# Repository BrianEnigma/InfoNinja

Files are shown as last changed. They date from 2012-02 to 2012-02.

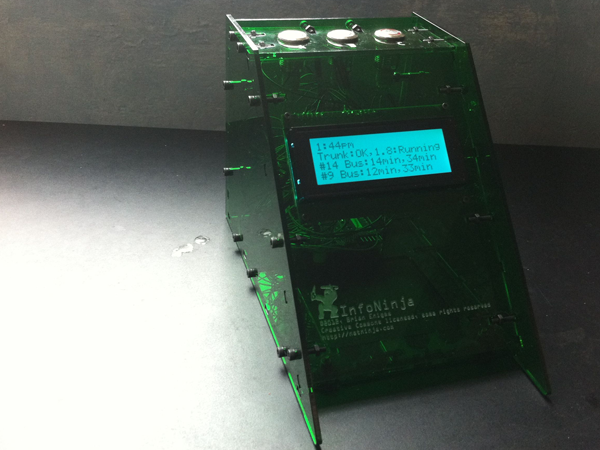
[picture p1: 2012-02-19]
design_documents/front_view.png

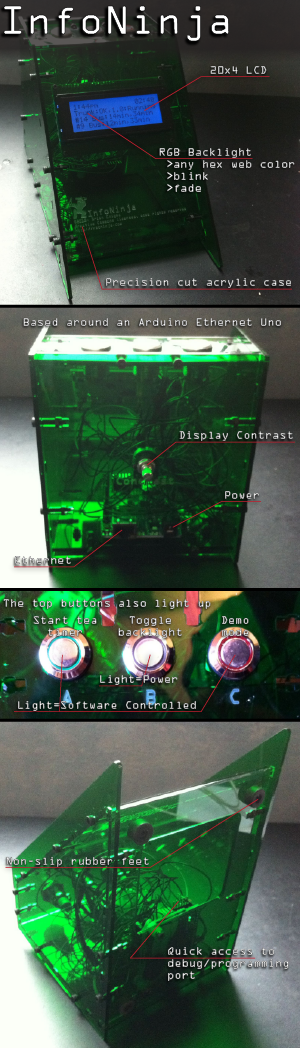
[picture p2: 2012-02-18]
design_documents/hardware_overview.png

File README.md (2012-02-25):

#InfoNinja

InfoNinja is an Open Source Ethernet-connected desktop heads-up display. It works in tandem with a desktop computer to give you an at-a-glance secondary display of both text and ambient (color/blink/fade) information.

It is also a tea timer.

More detailed information and instructions about InfoNinja can be found at <http://netninja.com/projects/infoninja/>.

#Overview

There are two pieces to InfoNinja, each split into its own section:

 - [Hardware/Firmware](http://netninja.com/projects/infoninja/hardware/)
 - [Software](http://netninja.com/projects/infoninja/software/)

The hardware is the InfoNinja box itself.  The firmware runs within InfoNinja and provides a lightweight REST-enabled web server.  It receives commands over the network and updates the text and lights.

The software runs on a desktop computer.  It can query various environmental conditions — things like weather, bus times, the stock market, recent Tweets, email counts, automated software builds — and then tell InfoNinja to do things like flash red or print status.

The two work in unison to give you any information you need.

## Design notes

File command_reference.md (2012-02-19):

#InfoNinja Command Reference

for firmware version 1.0

##Display Text

###URL

    http://x.x.x.x/print?n:my_text

###Parameters

- n : the 0-based line number to replace
- my_text : the URL-encoded text to write

###Description

This command displays text on the given line (from 0 to 3).  The entire line will be replaced with the text you give it, so any previously-displayed text will get overwritten, even if you're writing a shorter line.

The text is URL-encoded, so you will have to escape non-alphanumerics with percent-hex equivalents.  For example, "hello world" would be escaped to "hello%20world".  

You have up to 20 characters (after un-escaping) on each line, but remember that the last 5 characters of the first line (line 0) might be obscured by the tea timer countdown.

##Set BacklightColor

###URL

    http://x.x.x.x/lcdcolor?rrrgggbbb

###Parameters

- rrr : The 3-digit red value, from 000 to 255
- ggg : The 3-digit green value, from 000 to 255
- bbb : The 3-digit blue value, from 000 to 255

###Description

This command sets the LCD backlight color to any arbitrary value.  You should keep a few things in mind:

- The user can disable the solid-color backlight with the backlight toggle button.
- If you specify a backlight blink mode, that takes precedence over the solid color you define here.
- If you want to do more complex animations (such as blinking or fading), this is probably not the command to use.  The variable network delay can be unpredictable.  You likely want to use "Set Blink/Fade Mode" command, possibly extending that command to do a custom color pattern, if that is your desire.

##Set Button Lights

###URL

    http://x.x.x.x/buttonled?n

###Parameters

- n : light mode

####Description

This command enables, disables, or blinks the button LEDs.  The possible values for light mode are:

- 0 : disable button lights
- 1 : enable button lights
- 2 : blink button lights (the light toggles every second)

##Set Blink/Fade Mode

###URL

    http://x.x.x.x/blinkmode?n

###Parameters

- n : light mode

###Description

This command enables or disables the LCD backlight blink/fade mode.  The possible values for light mode are:

- 0 : Disable blinking/fading
- 1 : flash between bright yellow and dim yellow once a second
- 2 : flash between bright red and dim red once a second
- 3 : flash between bright blue and dim blue once a second
- 4 : fade between bright yellow and dim yellow
- 5 : fade between bright red and dim red
- 6 : fade between bright blue and dim blue

Note that this setting overrides any background color you may have set via the background-color command.

Also note that manually enabling the blue fade mode through software may be misleading.  This mode is automatically enabled if InfoNinja has not been communicated to in the last few minutes.  It is used to indicate that the displayed data may be stale.

##Button State

Retrieving the button state from the desktop software is specifically *not* supported.  Because the web server is single-threaded, it does not allow for cool Ajax-like blocking web requests (where the incoming web request is accepted, but holds off writing to it until the button state changes, simulating a synchronous action from an asynchronous query).  The desktop software would have to continually poll InfoNinja for the button state, then send updates to respond accordingly.  This introduces enough latency as to provide a rather poor user experience.  For this reason, the ability to query buttons has been intentionally omitted.

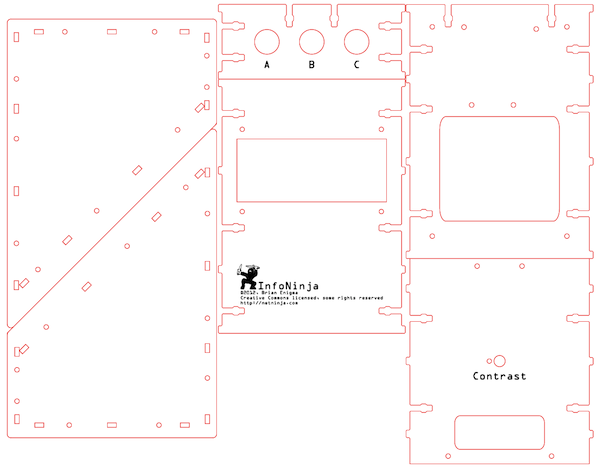
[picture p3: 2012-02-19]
design_documents/lasercut_preview.png

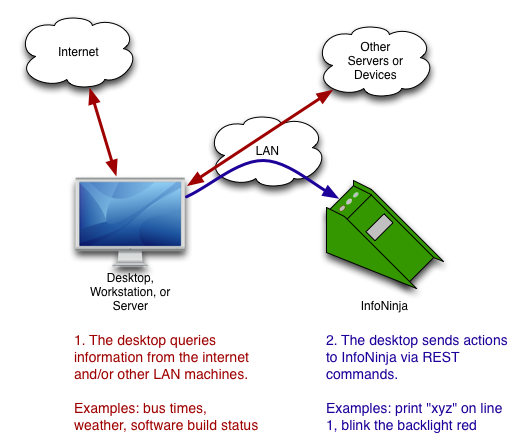
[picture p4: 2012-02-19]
design_documents/network_block_diagram.png

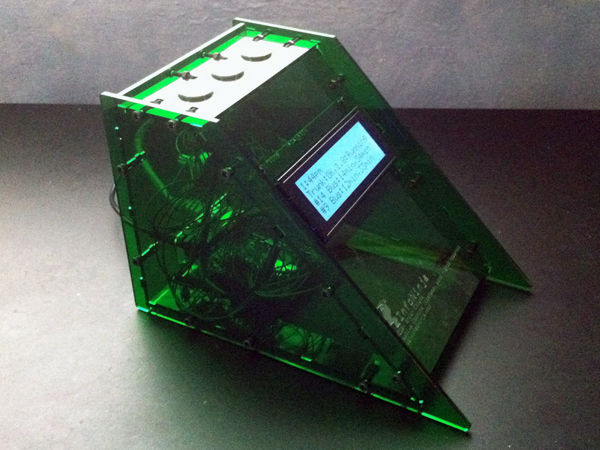
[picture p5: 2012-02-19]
design_documents/side_view.png

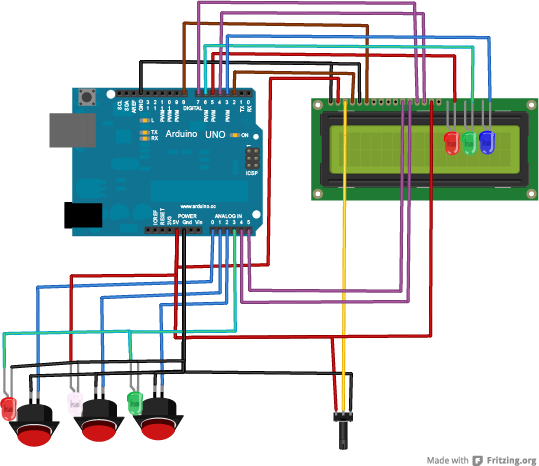
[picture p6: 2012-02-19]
schematics/InfoNinjaSchematic.png

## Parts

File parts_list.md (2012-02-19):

#InfoNinja Parts List

1. Obtain the tools you might need
    - Wire
    - Solder
	- [Headers](http://www.adafruit.com/products/400) to connect to the Arduino (or a breakout board such as the [Proto-Shield](http://www.adafruit.com/products/51) or [Wingshield](http://www.adafruit.com/products/196), if that’s your style)
    - etc.
2. Obtain electronics parts
    - [Arduino Ethernet](http://www.adafruit.com/products/418)
	- [AC Adapter](http://www.adafruit.com/products/63)
    - [20x4 RGB LCD](http://www.adafruit.com/products/499)
    - [Contrast knob](http://www.adafruit.com/products/562) (10K panel-mount potentiometer)
    - [Red LED pushbutton](http://www.adafruit.com/products/559)
    - [Green LED pushbutton](http://www.adafruit.com/products/560)
    - [White LED pushbutton](http://www.adafruit.com/products/558)
    - Ethernet cable
    - [FTDI Friend](https://www.adafruit.com/products/284) (for programming)
    - Mini-USB cable (for programming)
3. Obtain hardware
    - [16M3 screws](http://www.mcmaster.com/#91290A120), #91290A120
    - [M3 nuts](http://www.mcmaster.com/#98676A100), #98676A100
    - [10M2 screws](http://www.mcmaster.com/#91290A017), #91290A017
    - [M2 nuts](http://www.mcmaster.com/#90591A111), #90591A111
    - [8M3 Spacers](http://www.mcmaster.com/#93657A143), #93657A143
	- [M3 Nylon Washers](http://www.mcmaster.com/#95610A130), #95610A130
    - [Rubber feet](http://www.mcmaster.com/#9540K51), #9540K51
4. Obtain laser-cut parts
    - Laser-cut the case

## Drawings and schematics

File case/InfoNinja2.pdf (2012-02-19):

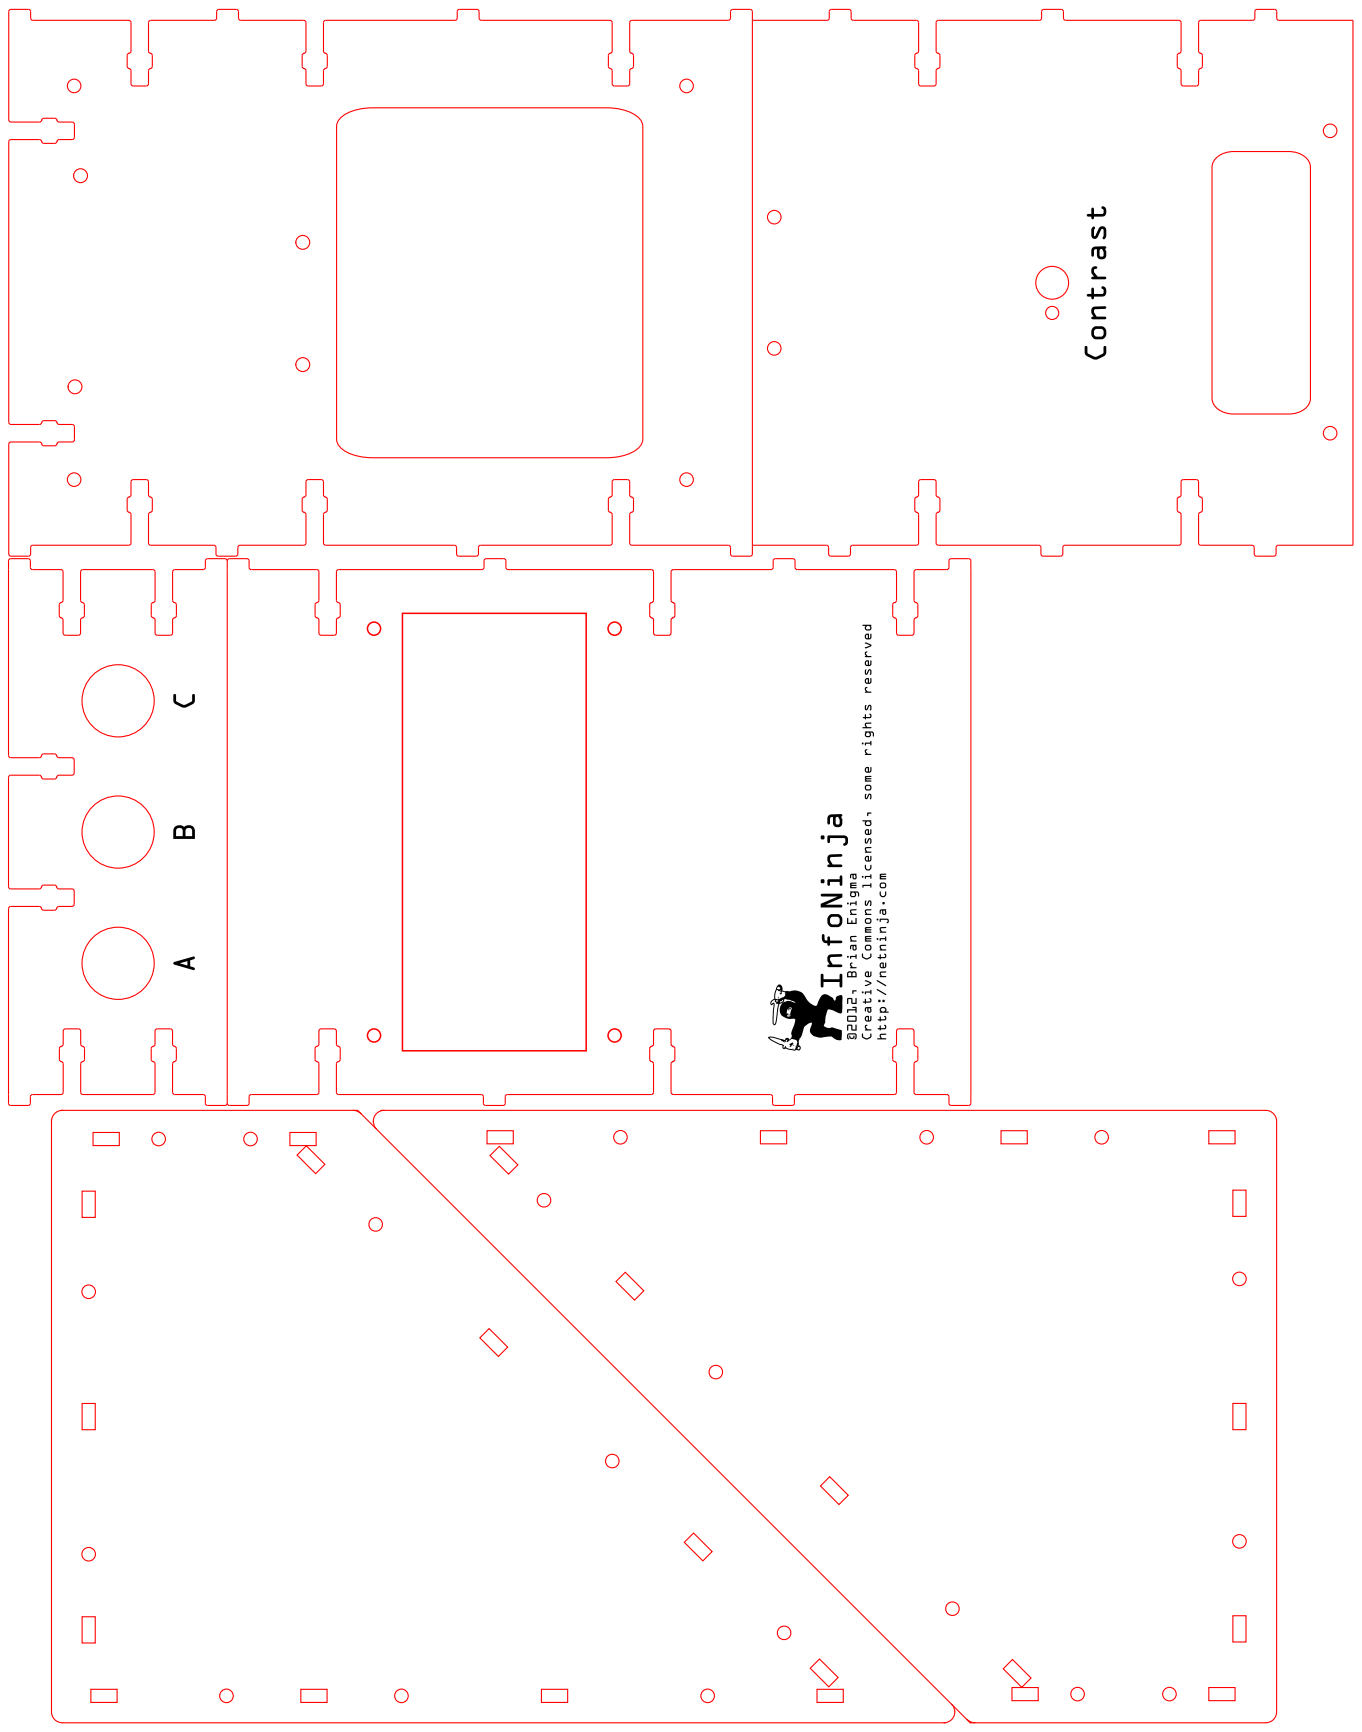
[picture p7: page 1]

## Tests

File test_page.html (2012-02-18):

InfoNinja's IP Address:

- LCD Text
  - Print Hello (http://10.0.1.15/print?0:HELLO)
  - Print Ninja (http://10.0.1.15/print?0:Ninja)
- Button LEDs
  - Button Lights On (http://10.0.1.15/buttonled?1)
  - Button Lights Off (http://10.0.1.15/buttonled?0)
  - Button Lights Blink (http://10.0.1.15/buttonled?2)
- LCD Backlight Colors
  - Backlight Off (http://10.0.1.15/lcdcolor?000000000)
  - Backlight White (http://10.0.1.15/lcdcolor?255255255)
  - Backlight Red (http://10.0.1.15/lcdcolor?255000000)
  - Backlight Green (http://10.0.1.15/lcdcolor?000255000)
  - Backlight Blue (http://10.0.1.15/lcdcolor?000000255)
  - Backlight Yellow (http://10.0.1.15/lcdcolor?255255000)
  - Backlight Purple (http://10.0.1.15/lcdcolor?255000255)
  - Backlight Cyan (http://10.0.1.15/lcdcolor?000255255)
  - No Blink (http://10.0.1.15/blinkmode?0)
  - Flash Yellow (http://10.0.1.15/blinkmode?1)
  - Flash Red (http://10.0.1.15/blinkmode?2)
  - Flash Blue (http://10.0.1.15/blinkmode?3)
  - Fade Yellow (http://10.0.1.15/blinkmode?4)
  - Fade Red (http://10.0.1.15/blinkmode?5)
  - Fade Blue (http://10.0.1.15/blinkmode?6)

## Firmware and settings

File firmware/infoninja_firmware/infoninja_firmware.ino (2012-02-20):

// Required by Ethernet
#include <SPI.h>
// Ethernet
#include <Dhcp.h>
#include <Dns.h>
#include <Ethernet.h>
#include <EthernetClient.h>
#include <EthernetServer.h>
#include <EthernetUdp.h>
#include <util.h>
// LCD
#include <LiquidCrystal.h>
// Webduino -- https://github.com/sirleech/Webduino
#include <WebServer.h>
// Bounce (a Debounce library) -- http://arduino.cc/playground/Code/Bounce
#include <Bounce.h>

const int numCols = 20;
const int numRows = 4;
// 20 columns:          _2345678_1_2345678_2
#define STARTUP_LINE_1 "InfoNinja"
#define STARTUP_LINE_2 "v1.0"
#define STARTUP_LINE_3 "--------------------"
#define STARTUP_LINE_4 "Obtaining IP address"

// General state info
// (state info for specific features are near their associated functions)
unsigned char wroteLcdLine4 = 0;
unsigned char backlightOn = 1;
int backlightRed = 255;
int backlightGreen = 255;
int backlightBlue = 255;
unsigned char blinkMode = 0;
unsigned char blinkModePrevious = 0;
#define BLINK_MODE_NONE 0
#define BLINK_MODE_FLASH_YELLOW 1
#define BLINK_MODE_FLASH_RED 2
#define BLINK_MODE_FLASH_BLUE 3
#define BLINK_MODE_FADE_YELLOW 4
#define BLINK_MODE_FADE_RED 5
#define BLINK_MODE_FADE_BLUE 6
#define BLINK_MODE_INVALID 7
unsigned char blinkDirection = 0; // 0=down, 1=up -- mainly for fades, not blinks
unsigned char buttonLedBlink = 0; // 0 = off, 1 = blinking, lighted, 2 = blinking, unlighted
unsigned char staleCounter = 0;   // number of seconds since last [valid] server request
#define STALE_MAX_SECONDS 70      // complain (blink blue) if no contact in this amount of time
unsigned char staleTriggered = 0; // When transitioning from 1 to 0, reset LCD backlight state

// GPIO pins
#define LCD_D4     A5
#define LCD_D5     A4
#define LCD_D6      7
#define LCD_D7      4
#define LCD_RS      2
#define LCD_ENABLE  8
#define LCD_RED     5
#define LCD_GREEN   6
#define LCD_BLUE    3
#define BUTTON_RED_GREEN_LED  A3
#define BUTTON_GREEN          A0
#define BUTTON_WHITE          A1
#define BUTTON_RED            A2

byte mac[] = {0x90, 0xA2, 0xDA, 0x00, 0x75, 0xD9};

LiquidCrystal lcd(LCD_RS, LCD_ENABLE, LCD_D4, LCD_D5, LCD_D6, LCD_D7);
#define WEBSERVER_PREFIX ""
WebServer webserver(WEBSERVER_PREFIX, 80);
Bounce debounceGreen(BUTTON_GREEN, 100);
Bounce debounceWhite(BUTTON_WHITE, 200);
Bounce debounceRed(BUTTON_RED, 200);

byte clock[8] = {
  B01110,
  B10101,
  B10101,
  B10101,
  B10011,
  B10001,
  B01110,
};

#define MINUTES3 (3 * 60)
#define MINUTES5 (5 * 60)
#define MINUTES7 (7 * 60)

void helloCmd(WebServer &server, WebServer::ConnectionType type, char *url_tail, bool tail_complete)
{
    server.httpSuccess();
    if (type != WebServer::HEAD)
    {
        P(helloMsg) = "<h1>InfoNinja is alive!</h1>";
        server.printP(helloMsg);
    }
}

IPAddress whitelistedIP(0,0,0,0);

unsigned char securityValid(WebServer &server, WebServer::ConnectionType type, char *url_tail, bool tail_complete)
{
    // If/when WebServer exposes the client IP address, we can store the very first
    // connection's IP address here, then only accept future connections from
    // that IP.
    //
    // Unfortunatly, this requires monkeypatching the Arduino Ethernet library followed
    // by exposing that IP in the Webduino library.
    
    // If the whitelisted IP variable is empty, whitelist the current one
    if (whitelistedIP == INADDR_NONE)
    {
        //whitelistedIP = (remote IP address returned from server)
    }
    
    if (0 /* whitelistedIP != (remote IP address returned from server) */) // this would be an IP address comparison
    {
        P(helloMsg) = "<h1>FAIL: YOUR IP IS NOT WHITELISTED</h1>";
        server.printP(helloMsg);
        return 0;
    } else {
        staleCounter = 0; // ONLY reset upon valid connection
    }
    return 1;
}

char unescape(char *hexcode)
{
    char result = 0;
    for (int i = 0; i < 2; i++)
    {
        if (*hexcode >= '0' && *hexcode <= '9')
            result = result * 16 + *hexcode - '0';
        else if (*hexcode >= 'a' && *hexcode <= 'f')
            result = result * 16 + *hexcode - 'a' + 10;
        else if (*hexcode >= 'A' && *hexcode <= 'F')
            result = result * 16 + *hexcode - 'A' + 10;
        hexcode += 1;
    }
    return result;
}

// http://a.b.c.d/print?1/My_Message
void printCmd(WebServer &server, WebServer::ConnectionType type, char *url_tail, bool tail_complete)
{
    server.httpSuccess();
    if (!securityValid(server, type, url_tail, tail_complete))
        return;
    if (type != WebServer::HEAD && strlen(url_tail) >= 3)
    {
        int lineNumber = url_tail[0] - '0';
        if (lineNumber >= 0 && lineNumber <= 3)
        {
            char newValue[21] = {0};
            char *pos = url_tail + 2, *pos2 = &newValue[0];
            while (*pos && strlen(newValue) < 20)
            {
                if (*pos == '%' && *(pos + 1) != 0x00 && *(pos + 2) != 0)
                {
                    *pos2 = unescape(pos + 1);
                    pos += 3;
                    pos2 += 1;
                } else if (*pos == '+') {
                    *pos2 = ' ';
                    pos += 1;
                    pos2 += 1;
                } else {
                    *pos2 = *pos;
                    pos += 1;
                    pos2 += 1;
                }
            }
            lcd.setCursor(0, lineNumber); lcd.print("                    ");
            lcd.setCursor(0, lineNumber); lcd.print(newValue);
            if (3 == lineNumber)
                wroteLcdLine4 = 1;
            P(helloMsg) = "<h1>GOOD</h1>";
            server.printP(helloMsg);
        } else {
            P(helloMsg) = "<h1>ERROR</h1>";
            server.printP(helloMsg);
        }
    }
}

// http://a.b.c.d/lcdcolor?rrrgggbbb
void lcdColorCmd(WebServer &server, WebServer::ConnectionType type, char *url_tail, bool tail_complete)
{
    server.httpSuccess();
    if (!securityValid(server, type, url_tail, tail_complete))
        return;
    if (type != WebServer::HEAD && strlen(url_tail) >= 9)
    {
        int red = 0, green = 0, blue = 0;
        red   = (url_tail[0] - '0') * 100 + (url_tail[1] - '0') * 10 + (url_tail[2] - '0');
        green = (url_tail[3] - '0') * 100 + (url_tail[4] - '0') * 10 + (url_tail[5] - '0');
        blue  = (url_tail[6] - '0') * 100 + (url_tail[7] - '0') * 10 + (url_tail[8] - '0');
        if (red >= 0 && red <= 255 && green >= 0 && green <= 255 && blue >= 0 && blue <= 255)
        {
            analogWrite(LCD_RED,   255 - red);
            analogWrite(LCD_GREEN, 255 - green);
            analogWrite(LCD_BLUE,  255 - blue);
            backlightOn = 1;
            backlightRed = red;
            backlightGreen = green;
            backlightBlue = blue;
            blinkMode = blinkModePrevious = BLINK_MODE_NONE;
            P(helloMsg) = "<h1>GOOD</h1>";
            server.printP(helloMsg);
        } else {
            P(helloMsg) = "<h1>ERROR</h1>";
            server.printP(helloMsg);
        }
    }
}

// http://a.b.c.d/buttonled?x
void buttonLedCmd(WebServer &server, WebServer::ConnectionType type, char *url_tail, bool tail_complete)
{
    server.httpSuccess();
    if (!securityValid(server, type, url_tail, tail_complete))
        return;
    if (type != WebServer::HEAD && strlen(url_tail) >= 1)
    {
        buttonLedBlink = url_tail[0] == '2' ? 1 : 0;
        digitalWrite(BUTTON_RED_GREEN_LED, url_tail[0] == '0' ? LOW: HIGH);
        P(helloMsg) = "<h1>GOOD</h1>";
        server.printP(helloMsg);
    } else {
        P(helloMsg) = "<h1>ERROR</h1>";
        server.printP(helloMsg);
    }
}

// http://a.b.c.d/blinkmode?x
void blinkModeCmd(WebServer &server, WebServer::ConnectionType type, char *url_tail, bool tail_complete)
{
    server.httpSuccess();
    if (!securityValid(server, type, url_tail, tail_complete))
        return;
    if (type != WebServer::HEAD && strlen(url_tail) >= 1)
    {
        unsigned char value = url_tail[0] - '0';
        if (value >= BLINK_MODE_NONE && value < BLINK_MODE_INVALID)
        {
            blinkModePrevious = blinkMode;
            blinkMode = value;
            blinkDirection = 1;
            P(helloMsg) = "<h1>GOOD</h1>";
            server.printP(helloMsg);
        } else {
            P(helloMsg) = "<h1>ERROR</h1>";
            server.printP(helloMsg);
        }
    } else {
        P(helloMsg) = "<h1>ERROR</h1>";
        server.printP(helloMsg);
    }
}

void setup()
{
    int counter;
    // Set up LCD pins
    pinMode(LCD_D4, OUTPUT);
    digitalWrite(LCD_D4, LOW);
    pinMode(LCD_D5, OUTPUT);
    digitalWrite(LCD_D5, LOW);
    pinMode(LCD_RED, OUTPUT);
    pinMode(LCD_GREEN, OUTPUT);
    pinMode(LCD_BLUE, OUTPUT);
    
    // Set up button LED pins
    pinMode(BUTTON_RED_GREEN_LED, OUTPUT);
    
    // Test lights
    for (counter = 0; counter < 4; counter++)
    {
        analogWrite(LCD_RED,   (0 == counter || 3 == counter) ? 0 : 255);
        analogWrite(LCD_GREEN, (1 == counter || 3 == counter) ? 0 : 255);
        analogWrite(LCD_BLUE,  (2 == counter || 3 == counter) ? 0 : 255);
        digitalWrite(BUTTON_RED_GREEN_LED, counter % 2 == 0 ? HIGH : LOW);
        delay(750);
    }
    
    // Set up button pins
    pinMode(BUTTON_GREEN, INPUT);
    pinMode(BUTTON_WHITE, INPUT);
    pinMode(BUTTON_RED, INPUT);
    digitalWrite(BUTTON_GREEN, HIGH);
    digitalWrite(BUTTON_WHITE, HIGH);
    digitalWrite(BUTTON_RED, HIGH);
        
    // Set up LCD writer
    lcd.begin(numCols, numRows);
    lcd.createChar(1, clock);
    lcd.setCursor(0, 0); lcd.print(STARTUP_LINE_1);
    lcd.setCursor(0, 1); lcd.print(STARTUP_LINE_2);
    lcd.setCursor(0, 2); lcd.print(STARTUP_LINE_3);
    lcd.setCursor(0, 3); lcd.print(STARTUP_LINE_4);
    
    // Set up Ethernet
    Ethernet.begin(mac); // This blocks until we get a DHCP address!
    lcd.clear();
    lcd.setCursor(0, 0); lcd.print(STARTUP_LINE_1);
    
    // Set up web server
    webserver.setDefaultCommand(&helloCmd);
    webserver.addCommand("index.html", &helloCmd);
    webserver.addCommand("print", &printCmd); 
    webserver.addCommand("lcdcolor", &lcdColorCmd); 
    webserver.addCommand("buttonled", &buttonLedCmd); 
    webserver.addCommand("blinkmode", &blinkModeCmd); 
    webserver.begin();
    
    debounceGreen.update();
    debounceWhite.update();
    debounceRed.update();
    //Serial.begin(9600);
    //Serial.println("DEBUG START");
}

void toggleBacklight()
{
    if (backlightOn)
    {
        backlightOn = 0;
        analogWrite(LCD_RED,   255);
        analogWrite(LCD_GREEN, 255);
        analogWrite(LCD_BLUE,  255);
    } else {
        backlightOn = 1;
        analogWrite(LCD_RED,   255 - backlightRed);
        analogWrite(LCD_GREEN, 255 - backlightGreen);
        analogWrite(LCD_BLUE,  255 - backlightBlue);
    }
}

unsigned char demoTimer = 0;
unsigned char inDemo = 0; // 0 = not in demo mode, any other value is a demo mode state

void demo()
{
    unsigned int now = (millis() / 1000) % 10;
    if (now == demoTimer)
        return;
    //lcd.write(random(0x20, 0xFF));
    demoTimer = now;
    analogWrite(LCD_RED,   random(255));
    analogWrite(LCD_GREEN, random(255));
    analogWrite(LCD_BLUE,  random(255));
    digitalWrite(BUTTON_RED_GREEN_LED, demoTimer % 2 == 0 ? HIGH : LOW);
}

int teaTimerValue = -1; // -1 = not in tea timer mode, any other value is the current time
int teaTimerLastSecond = 0;

void doTeaTimer()
{
    unsigned int now = (millis() / 1000) % 10;
    if (now != teaTimerLastSecond)
    {
        teaTimerLastSecond = now;
        if (teaTimerValue > 0)
        {
            teaTimerValue = teaTimerValue - 1;
        } else {
            toggleBacklight();
        }
    }
    lcd.setCursor(15, 0);
    lcd.write(1);
    lcd.write(teaTimerValue / 60 + '0');
    lcd.write(':');
    lcd.write(teaTimerValue % 60 / 10 + '0');
    lcd.write(teaTimerValue % 10 + '0');
}

int blinkModeLastTime = 0;

unsigned char adjustBlink()
{
    unsigned int now = 0;
    unsigned char activeBlinkMode = blinkMode;
    if (staleCounter >= STALE_MAX_SECONDS)
        activeBlinkMode = BLINK_MODE_FADE_BLUE;
    
    if (activeBlinkMode == BLINK_MODE_NONE)
    {
        // restore background?
        return 0;
    }
    // Blinks are simple
    if (BLINK_MODE_FLASH_YELLOW == activeBlinkMode || BLINK_MODE_FLASH_RED == activeBlinkMode || BLINK_MODE_FLASH_BLUE == activeBlinkMode)
    {
        now = (millis() / 1000) % 10;
        if (blinkModeLastTime == now)
            return 0; // Operate only every second
        blinkModeLastTime = now;
        if (BLINK_MODE_FLASH_YELLOW == activeBlinkMode)
        {
            backlightRed = (backlightRed == 255) ? 128 : 255;
            backlightGreen = (backlightGreen == 255) ? 128 : 255;
            backlightBlue = 0;
        } else if (BLINK_MODE_FLASH_RED == activeBlinkMode) {
            backlightRed = (backlightRed == 255) ? 128 : 255;
            backlightGreen = 0;
            backlightBlue = 0;
        } else  { // blue
            backlightRed = 32;
            backlightGreen = 32;
            backlightBlue = (backlightBlue == 255) ? 128 : 255;
        }
    }
    // Fades have more complexity and state
    if (BLINK_MODE_FADE_YELLOW == activeBlinkMode || BLINK_MODE_FADE_RED == activeBlinkMode || BLINK_MODE_FADE_BLUE == activeBlinkMode)
    {
        now = (millis() / 10);
        if (blinkModeLastTime == now)
            return 0;
        //Serial.println(now);
        blinkModeLastTime = now;
        if (BLINK_MODE_FADE_YELLOW == activeBlinkMode)
        {
            // fade
            if (blinkDirection == 1 && backlightRed < 255)
                backlightRed = backlightRed + 1;
            else if (blinkDirection == 0 && backlightRed > 127)
                backlightRed = backlightRed - 1;
            if (blinkDirection == 1 && backlightGreen < 255)
                backlightGreen = backlightGreen + 1;
            else if (blinkDirection == 0 && backlightGreen > 127)
                backlightGreen = backlightGreen - 1;
            // switch                 
            if (blinkDirection == 1 && backlightRed == 255 && backlightGreen == 255)
                blinkDirection = 0;
            else if (blinkDirection == 0 && backlightRed <= 127 && backlightGreen <= 127)
                blinkDirection = 1;
            backlightBlue = 0;
        } else if (BLINK_MODE_FADE_RED == activeBlinkMode) {
            if (blinkDirection == 1 && backlightRed < 255)
                backlightRed = backlightRed + 1;
            else if (blinkDirection == 1 && backlightRed == 255)
                blinkDirection = 0;
            else if (blinkDirection == 0 && backlightRed > 127)
                backlightRed = backlightRed - 1;
            else if (blinkDirection == 0 && backlightRed <= 127)
                blinkDirection = 1;
            backlightGreen = 0;
            backlightBlue = 0;
        } else { // blue and/or stale
            if (blinkDirection == 1 && backlightBlue < 255)
                backlightBlue = backlightBlue + 1;
            else if (blinkDirection == 1 && backlightBlue == 255)
                blinkDirection = 0;
            else if (blinkDirection == 0 && backlightBlue > 127)
                backlightBlue = backlightBlue - 1;
            else if (blinkDirection == 0 && backlightBlue <= 127)
                blinkDirection = 1;
            backlightGreen = 32;
            backlightRed = 32;
        }
        //Serial.print(blinkMode); Serial.print(":"); Serial.print(activeBlinkMode); Serial.print(":"); Serial.print(blinkDirection); Serial.print(":");
        //Serial.print(backlightRed); Serial.print(","); Serial.print(backlightGreen); Serial.print(","); Serial.println(backlightBlue);
    }
    return 1;
}

void doBlink()
{
    unsigned char rc = adjustBlink();
    
    // If iw as just now disabled, reset the LCD state
    if (blinkModePrevious != blinkMode && BLINK_MODE_NONE == blinkMode)
    {
        rc = 0;
        blinkModePrevious = blinkMode;
        // Make white
        backlightRed = backlightGreen = backlightBlue = 255;
        // Restore to previous backlight enabled/disabled state
        toggleBacklight();
        toggleBacklight();
    }
    
    // If it changed update
    if (rc)
    {
        analogWrite(LCD_RED,   255 - backlightRed);
        analogWrite(LCD_GREEN, 255 - backlightGreen);
        analogWrite(LCD_BLUE,  255 - backlightBlue);
    }
}

unsigned char previousButtonBlinkTime = 0;
void doButtonBlink()
{
    if (0 == buttonLedBlink)
        return;
    unsigned int now = (millis() / 1000) % 10;
    if (previousButtonBlinkTime == now)
        return; // Operate only every second
    previousButtonBlinkTime = now;
    buttonLedBlink = (1 == buttonLedBlink) ? 2 : 1;
    digitalWrite(BUTTON_RED_GREEN_LED, 1 == buttonLedBlink ? HIGH : LOW);
}

unsigned char stalePreviousSecond = 0;

void countStale()
{
    unsigned int now = (millis() / 1000) % 10;
    if (staleTriggered && staleCounter < STALE_MAX_SECONDS)
    {
        staleTriggered = 0;
        backlightRed = backlightGreen = backlightBlue = 255;
        // Restore to previous backlight enabled/disabled state
        toggleBacklight();
        toggleBacklight();
    }
    if (now == stalePreviousSecond)
        return;
    stalePreviousSecond = now;
    if (staleCounter < STALE_MAX_SECONDS)
        staleCounter += 1;
    else
        staleTriggered = 1;
}

void loop()
{
    char buff[64];
    int len = 64;

    // Handle buttons
    debounceGreen.update();
    debounceWhite.update();
    debounceRed.update();
    if (debounceWhite.risingEdge())
        toggleBacklight();
    if (debounceRed.risingEdge())
    {
        if (0 == inDemo)
        {
            randomSeed(millis());
            inDemo = 1;
            //lcd.clear();
        } else {
            inDemo = 0;
        }
    }

    if (debounceGreen.risingEdge())
    {
        if (teaTimerValue == -1)
            teaTimerValue = MINUTES3;
        else if (teaTimerValue == 0)
            teaTimerValue = -1;
        else if (teaTimerValue <= MINUTES3)
            teaTimerValue = MINUTES5;
        else if (teaTimerValue <= MINUTES5)
            teaTimerValue = MINUTES7;
        else if (teaTimerValue <= MINUTES7)
            teaTimerValue = -1;
        if (-1 == teaTimerValue)
        {
            lcd.setCursor(15, 0);
            lcd.write("     ");
        }
    }
        
    if (inDemo)
    {
        teaTimerValue == -1;
        demo();
    } else {
        // Write the IP address on the last line, but only until a
        // client web connection writes something on that line.
        if (!wroteLcdLine4)
        {
            lcd.setCursor(0, 3);
            lcd.print(Ethernet.localIP());
        }
        countStale();
        doBlink();
        doButtonBlink();
        
        // Print buttons
#if 0
        lcd.setCursor(17, 3);
        if (digitalRead(BUTTON_GREEN))
            lcd.write('_');
        else
            lcd.write('*');
        if (digitalRead(BUTTON_WHITE))
            lcd.write('_');
        else
            lcd.write('*');
        if (digitalRead(BUTTON_RED))
            lcd.write('_');
        else
            lcd.write('*');
#endif
    
        buff[0] = 0;
        webserver.processConnection(buff, &len);
    }
    if (teaTimerValue != -1)
        doTeaTimer();
}

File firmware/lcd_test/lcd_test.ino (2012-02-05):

#include <LiquidCrystal.h>

// LCD Test
// App to test the wiring of the LCD.  I have it wired to some pretty weird pins
// because I'm using an Arduino Ethernet Uno and I need some PWMs available for 
// the backlight coloring.

const int numCols = 20;
const int numRows = 4;

//            rs, enable     d4  d5  d6 d7
LiquidCrystal lcd(2,  8,     A5, A4, 7, 4);

void setup()
{
    pinMode(A4, OUTPUT);
    digitalWrite(A4, LOW);
    pinMode(A5, OUTPUT);
    digitalWrite(A5, LOW);
    lcd.begin(numCols, numRows);
    lcd.print("hello, world!");
}

void loop()
{
    // set the cursor to column 0, line 1
    // (note: line 1 is the second row, since counting begins with 0): 
    lcd.setCursor(0, 1);
    // print the number of seconds since reset:    
    //lcd.print(millis()/1000);
}

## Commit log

2012-02-05 Initial project files
    [InfoNinja.fzz]
2012-02-05 Basic schematic, exported from Fritzing document
2012-02-13 Hardware up, basic firmware working
    [InfoNinja.fzz]
2012-02-18 Fixed up fades and blinks
    [infoninja_firmware.ino]
2012-02-18 Close to final: - Added blink button command - Added blue blink/fade commands - Added placeholder for security check - Added stale check, blinks blue if no contact for 70 seconds
2012-02-18 Fix transition from fade/blink to stale
    [infoninja_firmware.ino]
2012-02-19 Re-export latest schematic images
2012-02-19 Laser-cut case files
2012-02-19 Web preview of laser cut case file
2012-02-19 arduino mechanical layout -- hole locations
2012-02-19 First step of rename dir with case change
    The Mac has a non-case-sensitive filesystem that preserves case, so you can't rename "Datasheets" to "datasheets" in one step because they're the same name!
2012-02-19 Second step of case change
    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
2012-02-19 Moved files out of root folder into subfolders
    [InfoNinja.fzz]
2012-02-19 Forgot to inventory the screws & nuts for the feet.
2012-02-19 Clean up readme
    - moved parts list to separate file
    - links out to assembly instructions
    - assorted cleanup
2012-02-20 Fix for Ruby urlescaping
    Ruby escapes spaces as + instead of %20
    [infoninja_firmware.ino]
2012-02-20 Framework for desktop service
    Includes time and trimet.
    Still missing is the conflict resolution for buttons and blink
2012-02-23 Visually, better handle threads that are slow to start up and stabilize.
2012-02-25 Added errored() callback. This is for better handling of errors, exceptions, and unexpected thread terminations in the UI (e.g. clearing data so you're not staring at stale information)
2012-02-25 Added tea-timer tagline to match website
2012-03-01 Basic thread retry logic -- can retry 3 times in a 5 minute period
2013-06-05 Point weather GPS to PDX airport. Freemont Bridge weather data is screwy.
2014-04-24 Better parallel display of Jenkins info
    Show both 'currently building' status and 'last build success' status as two
    separate fields rather than collapsing them into one.
